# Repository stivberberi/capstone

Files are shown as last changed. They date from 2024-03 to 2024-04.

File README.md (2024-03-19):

# Capstone

Repo to host all code associated with my final year undergraduate capstone
project at McMaster University. The project focuses on a self-regulating
tourniquet that uses sensors to determine the limb occlusion pressure of a
patient to auto-adjust the cuff pressure to match.

## Setting up ESP32 Project

First setup the project by setting the target and menu options (e.g.,
clock-speed, etc.):

- idf.py set-target esp32
- idf.py menuconfig -> optional if you want to use defualt configs

Note: using ESP-IDF v5.2.1, where ADC_ATTEN_DB_12 has been defined in place of
ADC_ATTEN_DB_11.

### Flashing

1. `idf.py build`
2. `idf.py flash {-p PORT}` -> idf.py will try to find the proper port on its
   own so -p is optional. Will also automatically build so previous command is
   unnecessary.
3. `idf.py monitor {-p PORT}` -> Used to monitor the serial output

Alternatively, can combine all of the above into one command:
`idf.py flash monitor`

### Serial Plotting

To aid with plotting pressure sensor data, the
`serial_plotter/serial_plotter.py` script can be used to plot data.

## Project Layout

- main/capstone.c -> Main app code, calls all other components
- components/ -> Directory containing all project components; each has its own
  CMakeLists.txt file
- components/pressure_sensor/ -> Pressure sensor related code; setup of sensor,
  ADC reading, etc.

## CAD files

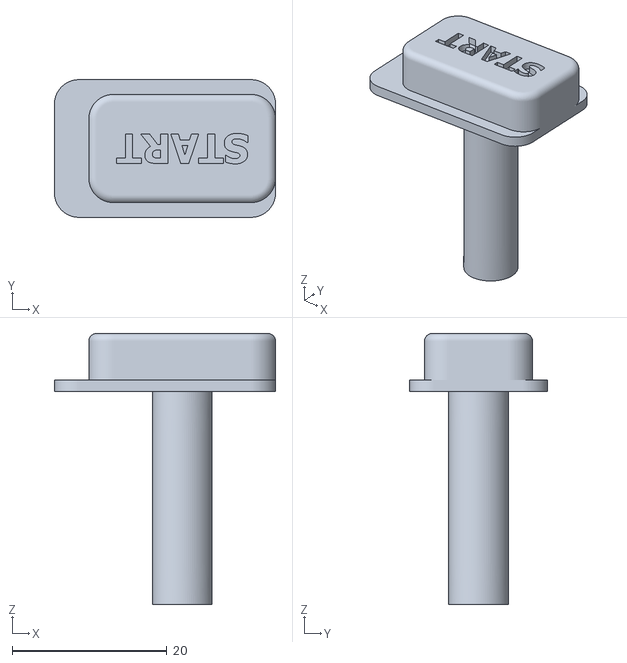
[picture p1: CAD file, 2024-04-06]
Cad Housing/PCB Housing Components - stl/Button - START.stl
28.6 x 17.8 x 35.0

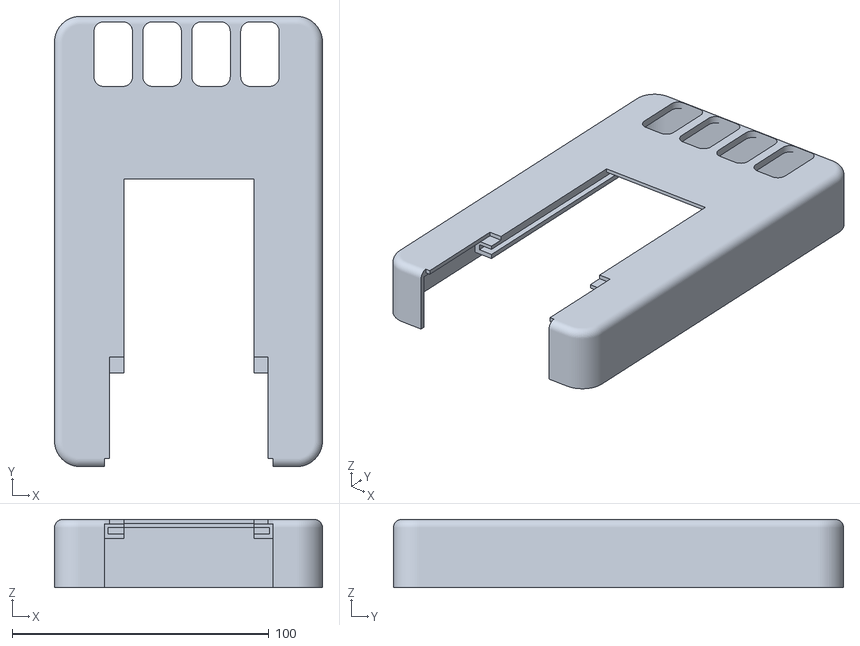
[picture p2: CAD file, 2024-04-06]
Cad Housing/PCB Housing Components - stl/Top Housing.stl
104.4 x 175.4 x 26.5

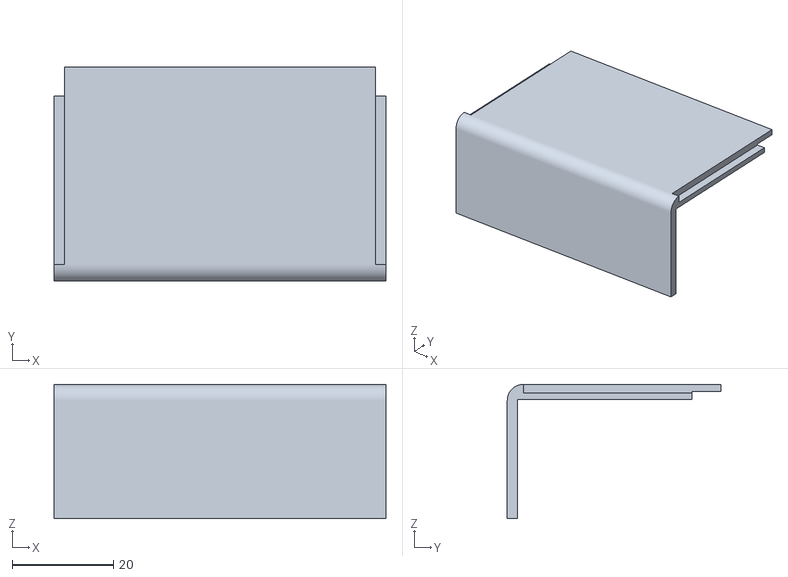
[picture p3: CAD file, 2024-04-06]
Cad Housing/PCB Housing Components - stl/Lid Cover.stl
65.5 x 42.1 x 26.5

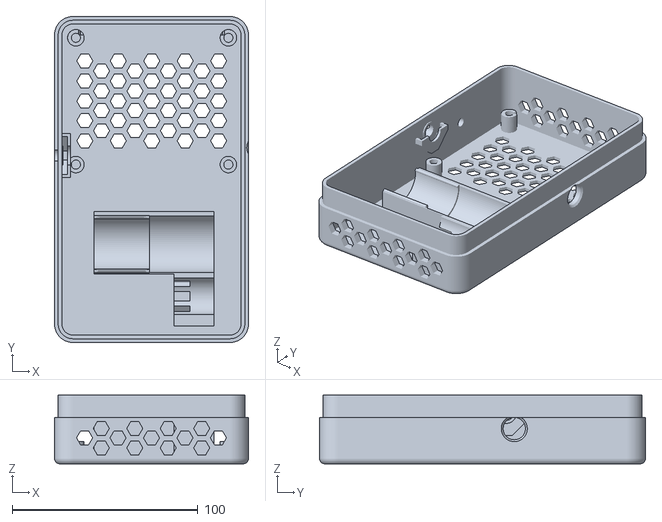
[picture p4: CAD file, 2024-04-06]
Cad Housing/PCB Housing Components - stl/Bottom Housing.stl
104.4 x 175.4 x 37.0

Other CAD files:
Cad Housing/PCB Housing Components - stl/Button - DOWN.stl
Cad Housing/PCB Housing Components - stl/Button - ONOFF.stl
Cad Housing/PCB Housing Components - stl/Button - UP.stl
Cad Housing/PCB Housing Components/Bottom Housing.ipt
Cad Housing/PCB Housing Components/Button - DOWN.ipt
Cad Housing/PCB Housing Components/Button - ONOFF.ipt
Cad Housing/PCB Housing Components/Button - START.ipt
Cad Housing/PCB Housing Components/Button - UP.ipt
Cad Housing/PCB Housing Components/Button Cover.ipt
Cad Housing/PCB Housing Components/Gage Stand.ipt
Cad Housing/PCB Housing Components/Lid Cover.ipt
Cad Housing/PCB Housing Components/PCB Housing.iam
Cad Housing/PCB Housing Components/Pump.ipt
Cad Housing/PCB Housing Components/Silicone Arm Bracket.ipt
Cad Housing/PCB Housing Components/Solenoid Valve.ipt
Cad Housing/PCB Housing Components/Top Housing.ipt
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

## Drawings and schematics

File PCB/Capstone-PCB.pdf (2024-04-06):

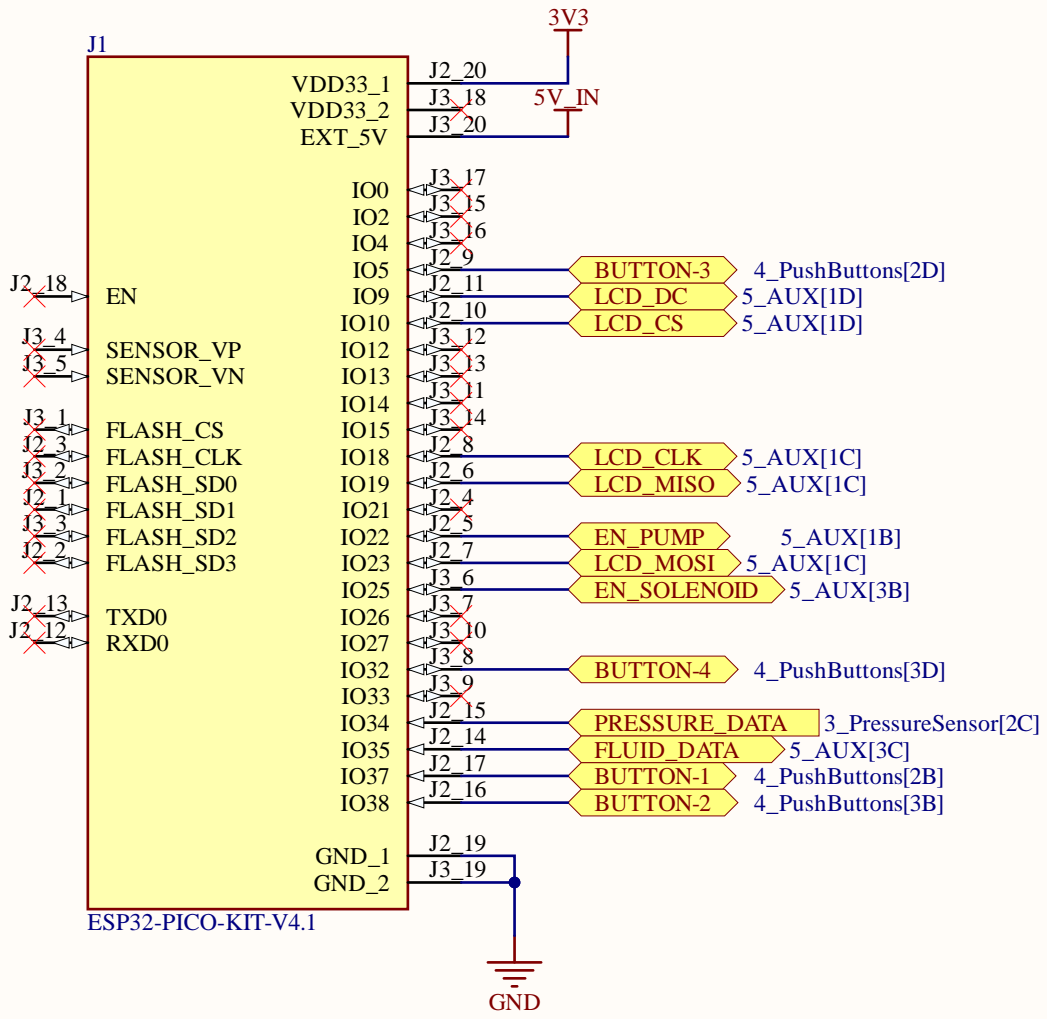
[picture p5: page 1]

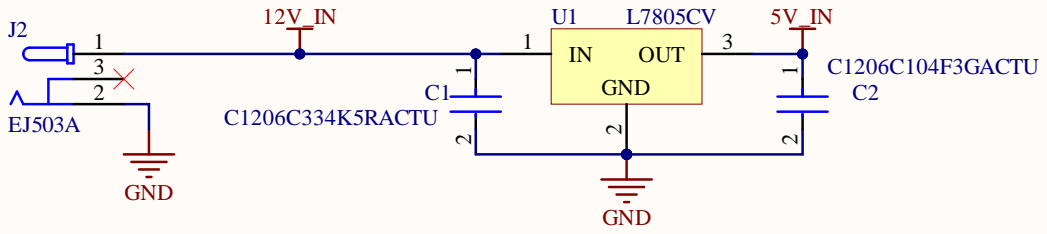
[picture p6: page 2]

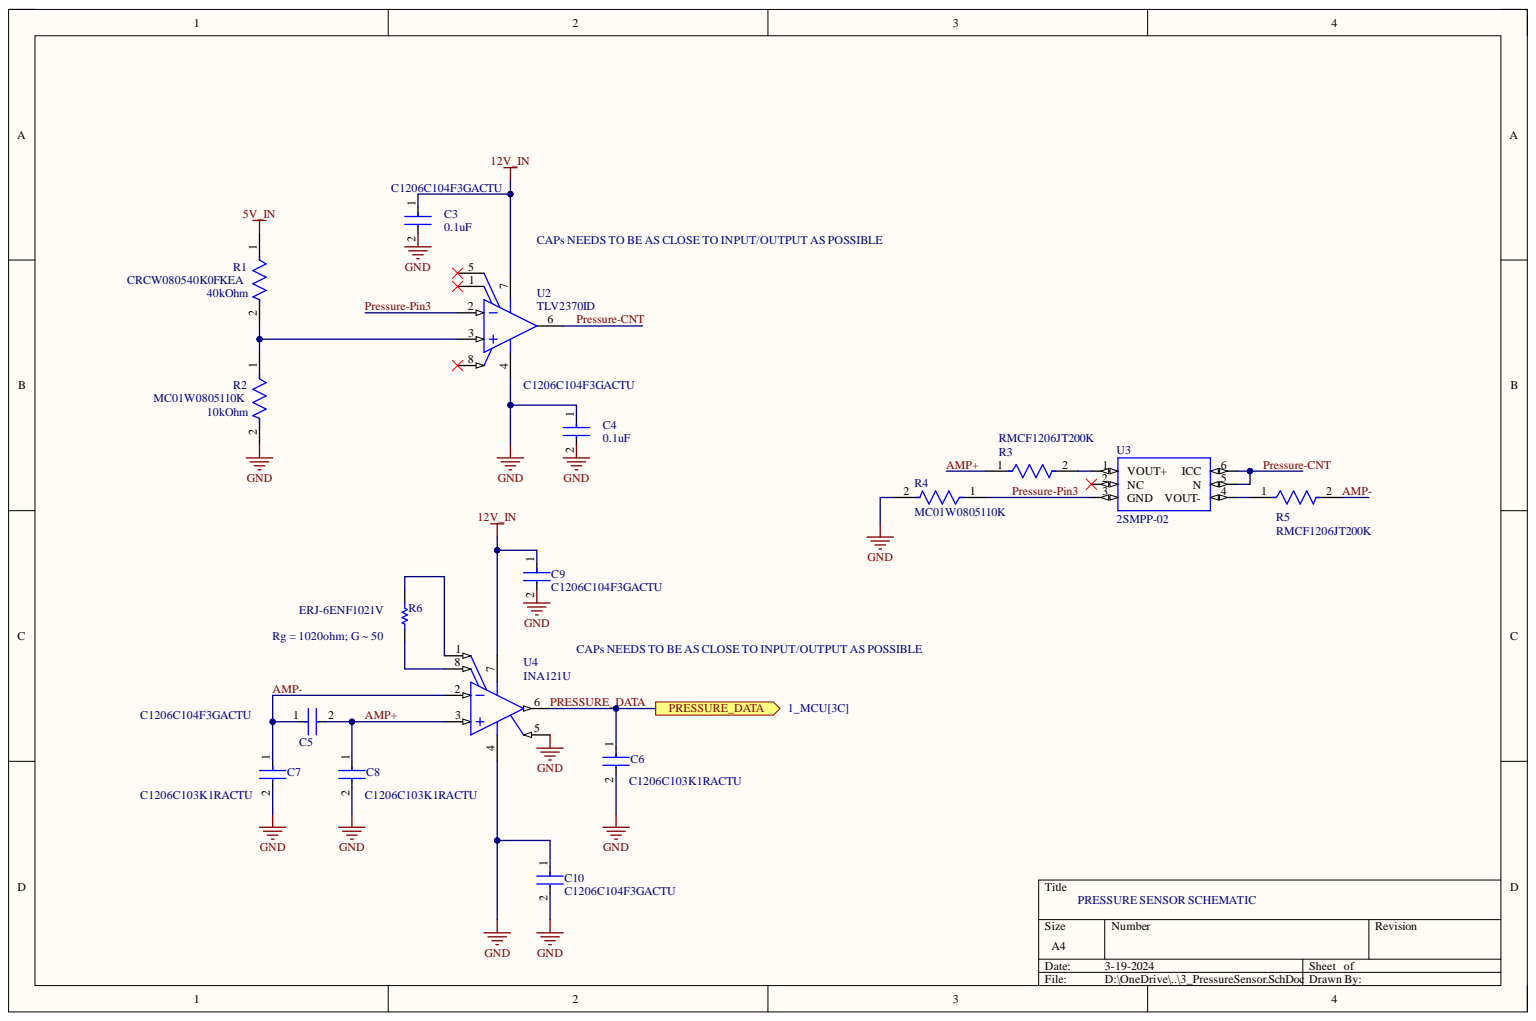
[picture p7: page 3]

CAPs NEEDS TO BE AS CLOSE TO INPUT/OUTPUT AS POSSIBLE

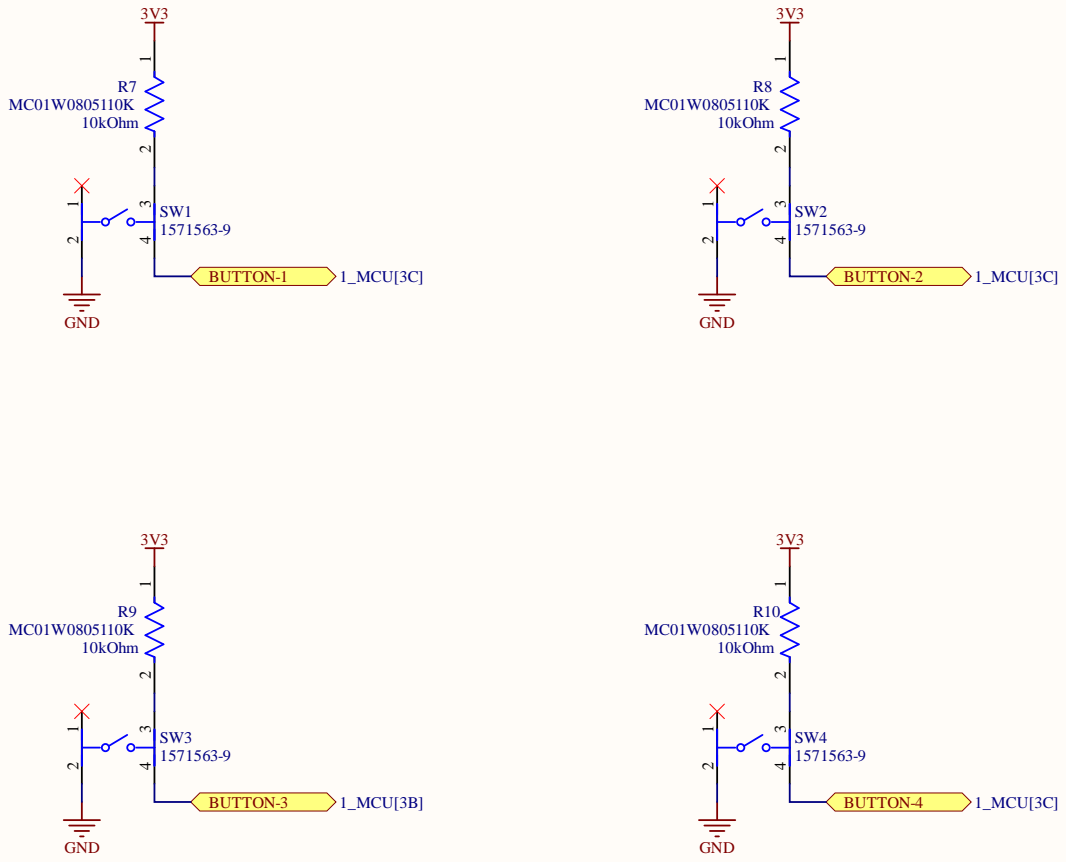
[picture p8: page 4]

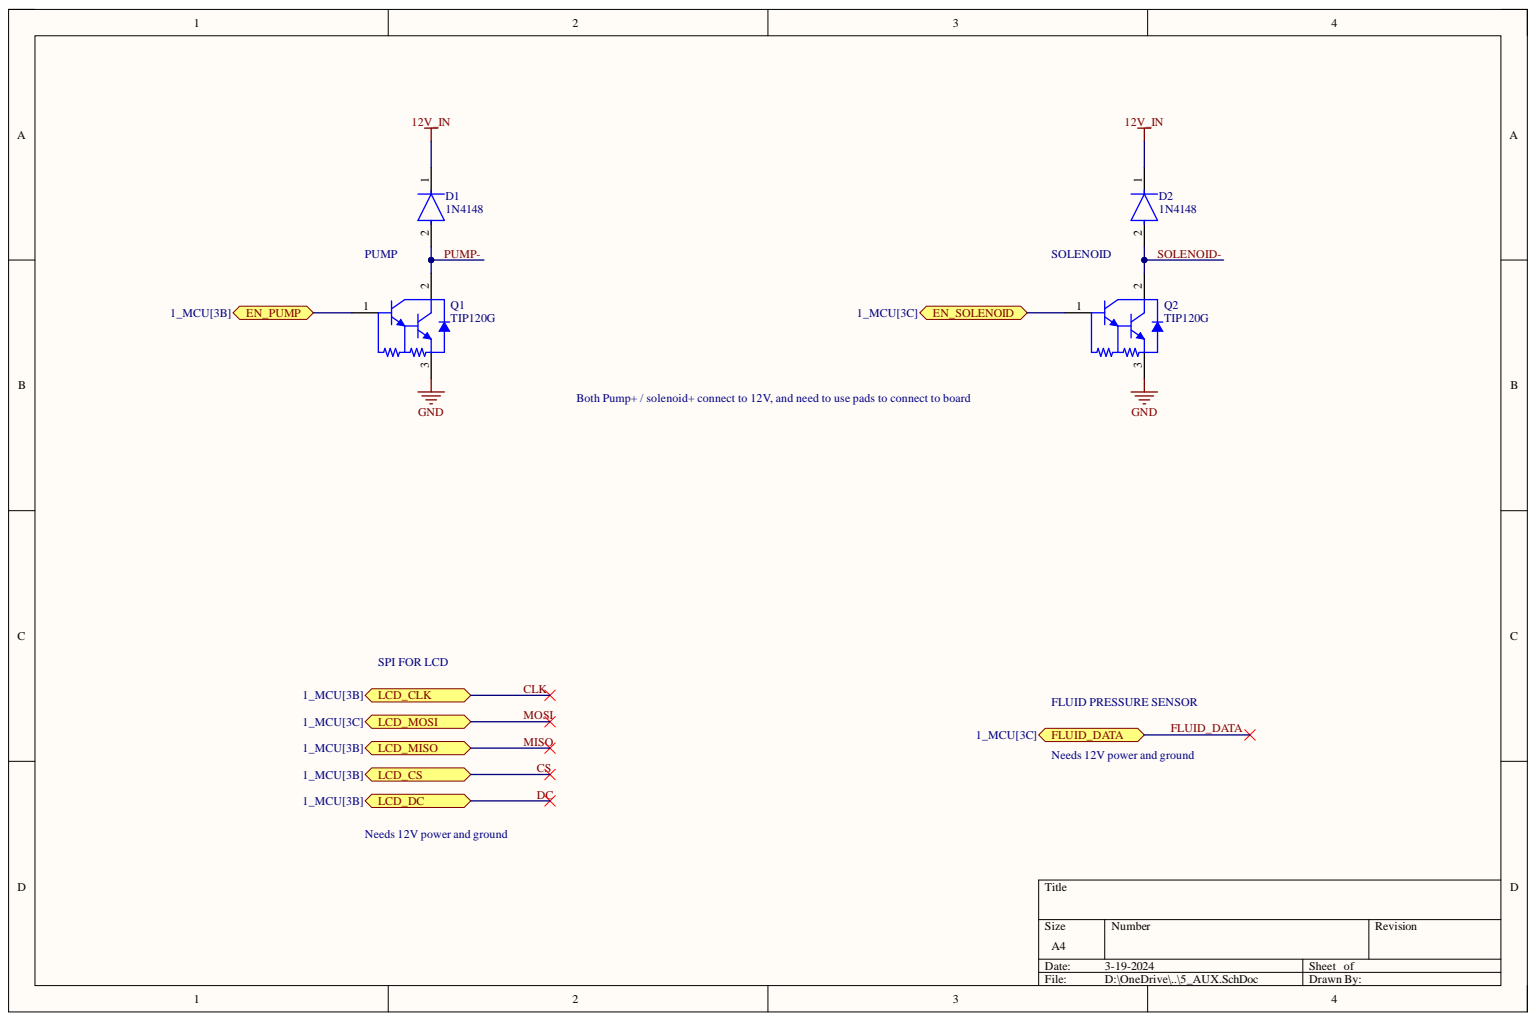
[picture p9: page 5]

Both Pump+ / solenoid+ connect to 12V, and need to use pads to connect to board

Needs 12V power and ground

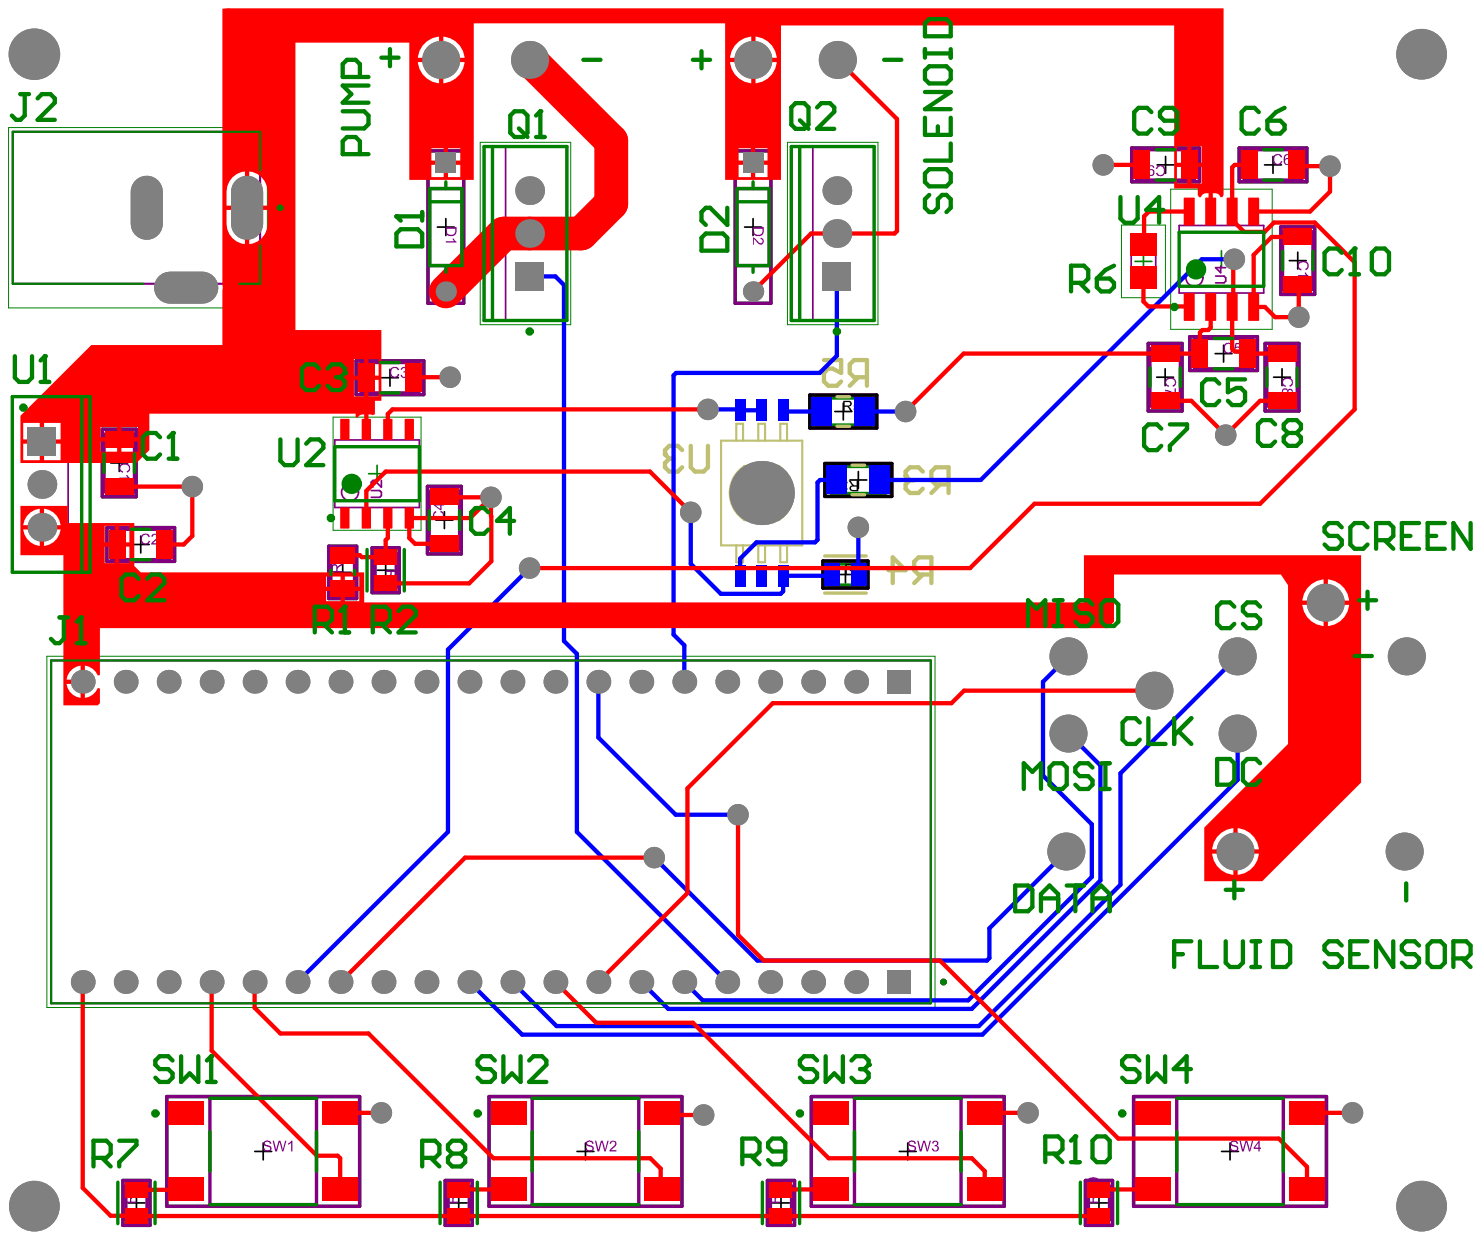
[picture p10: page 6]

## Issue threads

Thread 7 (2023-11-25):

Add better pressure data tracking

stivberberi, 2023-11-25:
Create an array (or similar data structure) to house pressure sensor data, such that the main task can easily access the data to control the motor with it.

Closed 2024-03-20.

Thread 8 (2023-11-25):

Add serial monitoring to allow commands to be sent for pressure control

stivberberi, 2023-11-25:
Allow for pressure control via serial input.

Ex. In `idf.py monitor` or `serial_plotter.py` we could send commands to the ESP32 to allow for set points of pressure. Run the motor until this setpoint is reached.

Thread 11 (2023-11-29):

Add solenoid control

stivberberi, 2023-11-29:
Add solenoid control functionality (via pin 25). Circuit was setup with a Darlington transistor according to [this](https://bc-robotics.com/tutorials/controlling-a-solenoid-valve-with-arduino/) guide.

Switching pin on = solenoid turns on.
Switching pin off = solenoid turns off.

Want this coupled with the air pump control as the solenoid acts as an exhaust valve for the system.

Closed 2023-11-29.

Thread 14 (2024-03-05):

Add fluid pressure sensor support

stivberberi, 2024-03-05:
Using an industrial fluid pressure sensor in place of an intra-arterial pressure reader for our demo device.

Pressure sensor we bought: https://mm.digikey.com/Volume0/opasdata/d220001/medias/docus/2247/114991178_Web.pdf

Image of
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

Closed 2024-04-07.

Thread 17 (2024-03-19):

Get working demo

stivberberi, 2024-03-19:
Get a working demo with the fluid pressure sensor, with simple pressure tracking implemented at this stage (more complex tracking with  a PID controller and PWM controlled motor to be added later).

Main goals:
* Get fluid pressure data
* Turn on motor while internal cuff pressure is < fluid pressure
* Turn motor off when it reaches within a threshold of fluid pressure.
* Open solenoid if you overshoot
* Turn motor back on anytime we fall outside of the threshold.

Closed 2024-04-05.

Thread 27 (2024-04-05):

Add better button flow

stivberberi, 2024-04-05:
On/Off -> First press = screen on; second press = deflate cuff; press & hold = everything off

Start -> First press = start inflation; second press = pause / hold before hitting target pressure

Up = set target pressure higher

Down = set target pressure lower

Closed 2024-04-05.

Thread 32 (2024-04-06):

Add Pobe's CAD files

stivberberi, 2024-04-06:
Added the following files and also reworked the directory structure to have separate folders for CAD model, PCB model, and src code.

* CAD housing IPT files
* STL files
* Created in Autodesk Inventor

Closed 2024-04-06.

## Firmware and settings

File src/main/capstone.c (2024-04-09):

#include "FreeRTOSConfig.h"
#include "custom_button.h"
#include "esp_err.h"
#include "esp_log.h"
#include "freertos/FreeRTOS.h"
#include "iot_button.h"
#include "lcd_screen.h"
#include "portmacro.h"
#include "pressure_sensor.h"
#include "pump.h"
#include <stdbool.h>
#include <stdio.h>

static char *TAG = "Main";

#define TARGET_OFFSET 7.0            // kPa (7 = 52.5 mmHg)
#define TARGET_OFFSET_CHANGE 0.67    // kPa; interval to increase offset
#define TARGET_OFFSET_THRESHOLD 0.67 // kPa (0.67 = 5 mmHg)

// Used to simulate arterial readings to test pressure tracking
const double TEST_ARTERIAL_PRESSURES[5] = {0.80, 1.33, 2.0, 2.67, 3.33}; // kPa

// Self-Regulating Tourniquet Modes
typedef struct _mode {
  enum { ON, OFF } power_status;
  enum { INFLATED, DEFLATED, INFLATING, PAUSED } inflation_status;
  double target_offset; // offset from arterial to target pressure
  double current_arterial_pressure;
} TourniquetConfig;

static void power_button_clicked(void *arg, void *usr_data) {
  TourniquetConfig *tourniquet_configs = (TourniquetConfig *)usr_data;
  ESP_LOGD(TAG, "Power button pressed.");

  if (tourniquet_configs->power_status == OFF) {
    // Turn on LCD
    turn_on_off_lcd(true);
    tourniquet_configs->power_status = ON;
  } else {
    // acts as e-stop; deflate the cuff now
    stop_pump();
    stop_solenoid();
    tourniquet_configs->inflation_status = DEFLATED;
  }
}

static void power_button_long_press(void *arg, void *usr_data) {
  TourniquetConfig *tourniquet_configs = (TourniquetConfig *)usr_data;
  ESP_LOGD(TAG, "Power button long pressed.");

  if (tourniquet_configs->power_status == ON) {
    // turn off system
    turn_on_off_lcd(false);
    stop_solenoid();
    stop_pump();
    tourniquet_configs->power_status = OFF;
  }
}

static void start_button_clicked(void *arg, void *usr_data) {
  TourniquetConfig *tourniquet_configs = (TourniquetConfig *)usr_data;
  ESP_LOGD(TAG, "Start button pressed.");

  if (tourniquet_configs->inflation_status == DEFLATED) {
    // start the feedback loop
    tourniquet_configs->inflation_status = INFLATING;
    start_solenoid();
    start_pump();
  } else if (tourniquet_configs->inflation_status == PAUSED) {
    // unpause it
    tourniquet_configs->inflation_status = INFLATING;
  } else {
    // Inflated or currently inflating; either way set it to hold pressure
    tourniquet_configs->inflation_status = PAUSED;
    stop_pump();
    start_solenoid(); // in case it was deflating
  }
}

void up_button_clicked(void *arg, void *usr_data) {
  TourniquetConfig *tourniquet_configs = (TourniquetConfig *)usr_data;

  // increase target pressure by set margin
  tourniquet_configs->target_offset += TARGET_OFFSET_CHANGE; // kPa
}

void down_button_clicked(void *arg, void *usr_data) {
  TourniquetConfig *tourniquet_configs = (TourniquetConfig *)usr_data;

  // decrease target pressure by set margin
  tourniquet_configs->target_offset -= TARGET_OFFSET_CHANGE; // kPa
}

int convert_kpa_to_mmHg(double kpa_reading) {
  return (int)(kpa_reading * 7.50062);
}

void app_main(void) {
  // logs are called with an identifier tag and a message.
  ESP_LOGI(TAG, "Welcome to group 16's capstone!");

  // **************************************************************************
  // ----------------------------SETUP-----------------------------------------
  // **************************************************************************

  // ADC and calibration handles for the pressure sensor:
  adc_oneshot_unit_handle_t ps_adc_handle;
  adc_cali_handle_t ps_cali_handle;
  setup_ps_adc(&ps_adc_handle, &ps_cali_handle);

  // create pressure sensor single data queue.
  QueueHandle_t ps_queue = xQueueCreate(1, sizeof(double));
  configASSERT(ps_queue != 0);
  PsHandle ps_task_args = {
      .ps_adc_handle = &ps_adc_handle,
      .ps_cali_handle = &ps_cali_handle,
      .ps_queue = &ps_queue,
  };

  // create pressure sensor single data queue.
  QueueHandle_t fs_queue = xQueueCreate(1, sizeof(double));
  configASSERT(fs_queue != 0);
  FsHandle fs_task_args = {
      .fs_adc_handle = &ps_adc_handle,
      .fs_cali_handle = &ps_cali_handle,
      .fs_queue = &fs_queue,
  };

  TaskHandle_t read_ps_handle = NULL;
  xTaskCreate(read_ps_adc, "Reading Pressure Sensor", 2048, &ps_task_args, 8,
              &read_ps_handle);
  configASSERT(read_ps_handle);

  // Task for Fluid Pressure Sensor
  TaskHandle_t read_fs_handle = NULL;
  xTaskCreate(read_fs_adc, "Reading Fluid Pressure Sensor", 2048, &fs_task_args,
              8, &read_fs_handle);
  configASSERT(read_fs_handle);

  // setup LCD screen
  LCDStruct lcd_handles;
  setup_lcd(&lcd_handles);
  setup_lvgl_disp(&lcd_handles);

  // setup solenoid and air pump
  setup_pump_and_solenoid();
  double ps_data;
  double fs_data; // Fluid Sensor

  TourniquetConfig tourniquet_configs = {
      .power_status = OFF,
      .target_offset = TARGET_OFFSET,
      .inflation_status = DEFLATED,
      .current_arterial_pressure = 30.0,
  };

  // button set up
  button_handle_t power_button_handle = setup_button(37);
  iot_button_register_cb(power_button_handle, BUTTON_SINGLE_CLICK,
                         power_button_clicked, &tourniquet_configs);
  iot_button_register_cb(power_button_handle, BUTTON_LONG_PRESS_HOLD,
                         power_button_long_press, &tourniquet_configs);

  button_handle_t start_button_handle = setup_button(38);
  iot_button_register_cb(start_button_handle, BUTTON_SINGLE_CLICK,
                         start_button_clicked, &tourniquet_configs);

  button_handle_t up_button_handle = setup_button(5);
  iot_button_register_cb(up_button_handle, BUTTON_SINGLE_CLICK,
                         up_button_clicked, &tourniquet_configs);

  button_handle_t down_button_handle = setup_button(32);
  iot_button_register_cb(down_button_handle, BUTTON_SINGLE_CLICK,
                         down_button_clicked, &tourniquet_configs);

  // **************************************************************************
  // ------------------------END-SETUP-----------------------------------------
  // **************************************************************************
  char text[44];
  int target_pressure_idx = 0;
  double target_pressure = TEST_ARTERIAL_PRESSURES[target_pressure_idx];

  while (true) {
    vTaskDelay(100 / portTICK_PERIOD_MS);

    if (xQueueReceive(ps_queue, &ps_data, 100)) {
      // received data
      sprintf(text, "Cuff Pressure: %d mmHg", convert_kpa_to_mmHg(ps_data));
      update_pressure(lcd_handles.disp_handle, lcd_handles.cuff_pressure_label,
                      text);
      // print_to_lcd(&lcd_handles, text);
      ESP_LOGD(TAG, "Received %lf as ps_data", ps_data);
    }

    if (xQueueReceive(fs_queue, &fs_data, 100)) {
      // received data
      sprintf(text, "Arterial Pressure: %d mmHg", convert_kpa_to_mmHg(fs_data));
      update_pressure(lcd_handles.disp_handle,
                      lcd_handles.arterial_pressure_label, text);
      // print_to_lcd(&lcd_handles, text);
      ESP_LOGD(TAG, "Received %lf as fs_data", fs_data);
    }

    // print arterial pressure + offset
    target_pressure = fs_data + tourniquet_configs.target_offset;

    sprintf(text, "Target Pressure: %d mmHg\nOffset: %d mmHg",
            convert_kpa_to_mmHg(target_pressure),
            convert_kpa_to_mmHg(tourniquet_configs.target_offset));
    update_pressure(lcd_handles.disp_handle, lcd_handles.set_pressure_label,
                    text);

    /**
     Demo code: prints out the taret and current pressure readings so we can
     plot it to compare to other forms of PID controller*/
    ESP_LOGI(TAG, "Cuff Pressure: %d mmHg", convert_kpa_to_mmHg(ps_data));
    ESP_LOGI(TAG, "Target Pressure: %d mmHg",
             convert_kpa_to_mmHg(target_pressure));

    if (tourniquet_configs.inflation_status == INFLATING ||
        tourniquet_configs.inflation_status == INFLATED) {
      // continue to check this even if we are inflated in case we go outside
      // the pressure thresholds
      if (ps_data < target_pressure - TARGET_OFFSET_THRESHOLD) {
        // run pump and solenoid to reach target pressure
        start_pump();
        start_solenoid();
      } else if (ps_data > target_pressure + TARGET_OFFSET_THRESHOLD) {
        // above the threshold, release solenoid to get back
        stop_pump();
        stop_solenoid();
      } else {
        ESP_LOGI(TAG, "Reached target pressure");
        tourniquet_configs.inflation_status = INFLATED;
        stop_pump();
        start_solenoid();
        // For simulation; wait two seconds before moving to the next target
        // pressure but don't stop task execution so we keep sending logs
        if (target_pressure_idx == 5) {
          continue;
        } else {
          target_pressure_idx++;
          target_pressure = TEST_ARTERIAL_PRESSURES[target_pressure_idx];
        }
        continue;
      }
    }
  }
}

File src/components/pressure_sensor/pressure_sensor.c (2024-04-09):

#include "pressure_sensor.h"
#include "FreeRTOSConfig.h"
#include "adc_cali_schemes.h"
#include "esp_adc/adc_cali.h"
#include "esp_adc/adc_cali_scheme.h"
#include "esp_adc/adc_oneshot.h"
#include "esp_err.h"
#include "esp_log.h"
#include "freertos/FreeRTOS.h"
#include "hal/adc_types.h"
#include "portmacro.h"

#define MOVING_AVERAGE_WINDOW_SIZE 30

const static char *TAG = "Pressure_Sensor"; // used as the tag for ESP_LOG's

/*
 * Sets up the ADC for the pressure sensor.
 * Sets the adc_oneshot_unit_handle_t and adc_cali_handle_t parameters
 * */
void setup_ps_adc(adc_oneshot_unit_handle_t *ps_adc_handle,
                  adc_cali_handle_t *ps_cali_handle) {
  /*-------------ADC Init---------------*/
  adc_oneshot_unit_init_cfg_t ps_init_config = {.unit_id =
                                                    PRESSURE_SENSOR_ADC_UNIT};
  ESP_ERROR_CHECK(adc_oneshot_new_unit(&ps_init_config, ps_adc_handle));

  /*-------------ADC Config---------------*/
  adc_oneshot_chan_cfg_t ps_config = {
      .atten = PRESSURE_SENSOR_ADC_ATTENUATION,
      .bitwidth = ADC_BITWIDTH_DEFAULT // automatically sets highest resolution
  };
  ESP_ERROR_CHECK(adc_oneshot_config_channel(
      *ps_adc_handle, PRESSURE_SENSOR_ADC_CHANNEL, &ps_config));
  ESP_ERROR_CHECK(adc_oneshot_config_channel(
      *ps_adc_handle, FLUID_SENSOR_ADC_CHANNEL, &ps_config));
// Calibrate the ADC
#if ADC_CALI_SCHEME_LINE_FITTING_SUPPORTED
  ESP_LOGI(TAG, "Starting ADC calibration...");
  adc_cali_line_fitting_config_t cali_config = {
      .unit_id = PRESSURE_SENSOR_ADC_UNIT,
      .bitwidth = ADC_BITWIDTH_DEFAULT,
      .atten = PRESSURE_SENSOR_ADC_ATTENUATION,
      .default_vref = ADC_CALI_LINE_FITTING_EFUSE_VAL_EFUSE_VREF,
  };
  esp_err_t rc =
      adc_cali_create_scheme_line_fitting(&cali_config, ps_cali_handle);
  if (rc == ESP_OK) {
    ESP_LOGI(TAG, "ADC calibration successful.");
  }
#endif
}

double convert_voltage_to_pressure(int voltage_mv) {
  // NOTE: probably don't want to be calculating this everytime?
  // voltage_in * Max pressure / (Span Voltage * Gain)
  // Max pressure = 37 kPa, Span voltage = 31.0 mV, Gain ~= 100
  // Also subtract 3.3 from final, to account for ~2.5mV offset * ~100 gain
  double pressure = voltage_mv * 37.0 / (31 * 100) - 1.694838;
  return pressure;
}

double convert_voltage_to_fluid(int voltage_mv) {
  double voltage = voltage_mv / 1000; // now in volts
  // This is for the fluid pressure sensor; Vout: 0-5V; Working Pressure
  // Rate Range: 0-10 PSI
  // https://www.seeedstudio.com/Water-Pressure-Sensor-G1-4-1-2MPa-p-2887.html
  // double pressure = ((1.33333333) * (voltage / 5.0 - 0.1)) + offset;
  double offset = 0;
  // this is the linear equation for this new sensor
  double pressure = 68.9476 * (voltage) / (5.0) + offset;
  return pressure;
}

int findMax(double arr[], int n) {
  int max = arr[0]; // Start with the first element
  for (int i = 1; i < n; i++) {
    if (arr[i] > max) {
      max = arr[i]; // Update max if current element is greater
    }
  }
  return max;
}

double findAvg(double arr[], int n) {
  double sum = 0;

  for (int i = 0; i < n; i++) {
    sum += arr[i];
  }

  // Calculate average
  return (sum / n);
}

// take pressure sensor readings; meant to be run as RTOS task
void read_ps_adc(void *ps_args) {
  int index_moving_average = 0;

  double pressure_values[MOVING_AVERAGE_WINDOW_SIZE] = {0};
  double pressure_avg = 0.0;

  for (;;) {
    PsHandle_Ptr args = (PsHandle_Ptr)ps_args;
    int adc_raw_reading;
    int voltage; // millivolt reading

    ESP_ERROR_CHECK(adc_oneshot_read(
        *args->ps_adc_handle, PRESSURE_SENSOR_ADC_CHANNEL, &adc_raw_reading));
    // ESP_LOGI(TAG, "ADC raw reading: %d", adc_raw_reading);
    if (args->ps_cali_handle != NULL) {
      // get a voltage reading from the calibration configuration. Otherwise use
      // an estimated conversion.
      ESP_ERROR_CHECK(adc_cali_raw_to_voltage(*args->ps_cali_handle,
                                              adc_raw_reading, &voltage));
      // ESP_LOGI(TAG, "Calibrated voltage: %d mV", voltage);
    } else {
      // Max of 2450 mV from this:
      // https://docs.espressif.com/projects/esp-idf/en/v4.4/esp32/api-reference/peripherals/adc.html
      // Definitely might be wrong / needs updating / testing however.
      voltage = adc_raw_reading * 2450 / 4095;
      ESP_LOGD(TAG, "Uncalibrated voltage: %d voltage", voltage);
    }
    double converted_pressure = convert_voltage_to_pressure(voltage);
    ESP_LOGD(TAG, "Converted pressure: %lf kPa\n", converted_pressure);

    // add to moving average queue
    pressure_values[index_moving_average] = converted_pressure;
    pressure_avg = findAvg(pressure_values, MOVING_AVERAGE_WINDOW_SIZE);
    index_moving_average =
        (index_moving_average + 1) % MOVING_AVERAGE_WINDOW_SIZE;

    // pass converted pressure
    xQueueOverwrite(*args->ps_queue, &pressure_avg);

    // run once every 100 ms.
    vTaskDelay(100 / portTICK_PERIOD_MS);
    ESP_LOGD(TAG, "Raw voltage: %d", voltage);
    ESP_LOGD(TAG, "Converted AIR Pressure: %lf", converted_pressure);
  }
}
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

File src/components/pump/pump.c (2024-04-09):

#include "pump.h"
#include "driver/gpio.h"
#include "esp_err.h"
#include "esp_log.h"
#include "hal/gpio_types.h"

const static char *TAG = "Pump";

void setup_pump_and_solenoid() {
  ESP_LOGI(TAG, "Setting up air pump and solenoid GPIO...");

  gpio_config_t pump_gpio_config = {
      .intr_type = GPIO_INTR_DISABLE,
      .mode = GPIO_MODE_OUTPUT,
      .pin_bit_mask = (1UL << RELAY_GPIO),
      .pull_up_en = 0,
      .pull_down_en = 0,
  };
  gpio_config_t solenoid_gpio_config = {
      .intr_type = GPIO_INTR_DISABLE,
      .mode = GPIO_MODE_OUTPUT,
      .pin_bit_mask = (1UL << SOLENOID_GPIO),
      .pull_up_en = 0,
      .pull_down_en = 0,
  };
  ESP_ERROR_CHECK(gpio_config(&pump_gpio_config));
  ESP_ERROR_CHECK(gpio_config(&solenoid_gpio_config));
}

/*-----Pump Control-----*/
void start_pump() {
  ESP_LOGD(TAG, "Starting pump...");
  gpio_set_level(RELAY_GPIO, 1);
}

void stop_pump() {
  ESP_LOGD(TAG, "Stopping pump...");
  gpio_set_level(RELAY_GPIO, 0);
}

/*-----Solenoid Control-----*/
void start_solenoid() {
  ESP_LOGD(TAG, "Starting solenoid...");
  gpio_set_level(SOLENOID_GPIO, 1);
}

void stop_solenoid() {
  ESP_LOGD(TAG, "Stopping solenoid...");
  gpio_set_level(SOLENOID_GPIO, 0);
}

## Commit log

2023-11-17 Add pressure_sensor component
2023-11-19 Add pump component and add esp_adc requirement to pressure_sensor
2023-11-21 Added calibrated voltage readings to pressure sensor
2023-11-21 Add voltage to pressure conversion
2023-11-24 Setup pump gpio
2023-11-24 Setup demo of pump
2023-11-24 Change tag to be compatible with idf.py monitor filtering
2023-11-24 Add serial_plotter.py to plot pressure data
2023-11-24 Revert file changes from another branch
    [capstone.c, pump.c]
2023-11-24 Fix pump.h file as well
2023-11-25 Add pump start and stop functions
2023-11-29 Added solenoid control
2024-03-05 Fix pressure sensor slope
    [pressure_sensor.c]
2024-03-05 Add button component from IDF component registry
2024-03-10 Added button component and updated gitignore
2024-03-15 LCD turning on; insufficient buffer size errors
    [capstone.c, lcd_screen.c, lcd_screen.h]
2024-03-15 Fixed buffer sizing issue
    [lcd_screen.c, lcd_screen.h]
2024-03-18 swapped x and y res, fixed display issues
    [capstone.c, lcd_screen.c, lcd_screen.h]
2024-03-19 Make pressure readings a debug log
2024-03-20 Start adding buffer to store pressure data
2024-03-25 Holding pressures that we set
2024-03-30 Pressure sensor on PCB not working properly
    [capstone.c, lcd_screen.h, pressure_sensor.c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]
2024-03-30 Add start/stop button
2024-04-04 Add LCD orientation fixes
    [capstone.c, lcd_screen.c, lcd_screen.h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]
2024-04-04 Fix LCD horizontal and vertical pixels
    [lcd_screen.c, lcd_screen.h]
2024-04-05 Fixed Fluid Sensor errors
    [pressure_sensor.c, pressure_sensor.h]
2024-04-05 Start adding better button callbacks
2024-04-05 Add all button state machines
2024-04-06 Added PCB Files
    [1_MCU.SchDoc, 2_Power.SchDoc, 3_PressureSensor.SchDoc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]
2024-04-06 Cleaned up respository
    [PCB1.GBL, PCB1.GBO, PCB1.GBP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]
2024-04-06 Add pobes CAD files and move code into src/ directory
    [1_MCU.SchDoc, 2_Power.SchDoc, 3_PressureSensor.SchDoc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]
2024-04-06 Fix .DS_Store files
    [Bottom Housing.stl, Button - DOWN.stl, Button - ONOFF.stl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]
2024-04-07 Add logs and pressure tracking
2024-04-08 Update serial plotter to read pressures
2024-04-08 Logs not working when running, but do when paused
    [capstone.c]
2024-04-08 Sensor Working
2024-04-09 Fluid Sensor Working
